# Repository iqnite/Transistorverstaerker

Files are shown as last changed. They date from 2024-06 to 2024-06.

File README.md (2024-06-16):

# TO DO

- [ ] Berechnung
  - [x] Arbeitspunkt-Einstellung
    - [x] Welcher Ib soll verwendet werden (Datenblatt)?
  - [x] Stromverstärker (Basisschaltung)
  - [ ] AC-Berechnung (Ersatzschaltbild)
  - [ ] Kopplungskondensator (Böhmer?)
- [ ] Simulation
- [ ] PCB?
- [ ] Dokumentation

# Downloads

## Zip

**Finales Projekt:** [Herunterladen](https://github.com/iqnite/Transistorverstaerker/archive/refs/heads/main.zip)

**Simulation und Berechnungen:** [Herunterladen](https://github.com/iqnite/Transistorverstaerker/archive/refs/heads/sim.zip)

## Git

**Installation:** `winget install git`

**Einmaliger Download:** `git clone https://github.com/iqnite/Transistorverstaerker.git`

**Update:** 

1. `git fetch`
2. `git pull`

# Struktur

**Altium-Projektordner:** [Transistorverstaerker](https://github.com/iqnite/Transistorverstaerker/tree/sim/Transistorverstaerker)

**OneNote-Notizbuch mit Berechnungen:** [Berechnungen](https://github.com/iqnite/Transistorverstaerker/tree/sim/Berechnungen)

> [!IMPORTANT]
> Das Notizbuch ist nur im [Simulationsteil](https://github.com/iqnite/Transistorverstaerker/tree/sim) verfügbar.

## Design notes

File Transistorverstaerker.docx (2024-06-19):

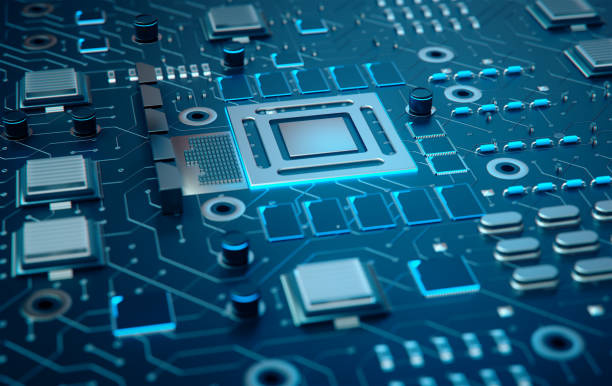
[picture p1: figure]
Elektronischen Chip, 3D-Rendering.

8. Mai 2024

SIMON salchner, Philipp Dona

3ahel/Gruppe 4

BETREUER: ERICH WALTER

ABGEGEBEN AM 19.6.2024

Zweistufiger Transitorverstärker

3. PROJEKT

# 1. Aufgabenstellung

## 1.1 Überblick

Das Ziel dieses Projekts besteht darin, einen zweistufigen Transistorverstärker zu entwerfen. Dieser besteht aus einer spannungsverstärkenden Emitter-Grundschaltung als Stufe 1, und einer stromverstärkenden Kollektor-Grundschaltung als Stufe 2.

## 1.2 Elektrische Vorgaben

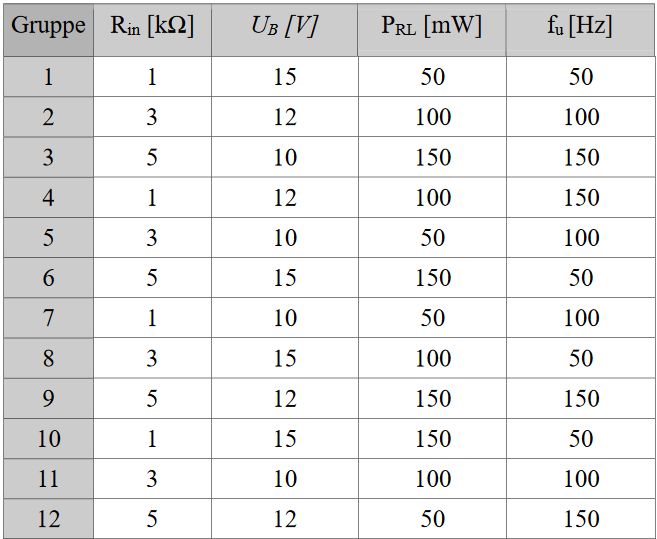
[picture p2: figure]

Die Schaltung wird mit 12 Volt betrieben. Wie in der Zeile 4 dargestellt, muss ein Rin von 1kΩ verwendet werden. Die Leistung am Ausgang PRL soll 100 mW groß sein und die Frequenz fu soll 150 Hz betragen. Ebenfalls war die Vorgabe, die Vu möglichst verzerrungsfrei zu maximieren. Alle weiteren Parameter konnten selbst festgelegt werden und mussten im Berechnungsteil dokumentiert werden.

## 1.3 Sonstige Vorgaben

Beim Erstellen und Aufbau der Schaltung dürfen ausschließlich Bauteile verwendet werden, die im HTL-Bauteilkit enthalten sind.

# 2. Schaltung und Schaltungsbeschreibung

## 2.1 Schaltungsbeschreibung

Diese Schaltung ist ein zweistufiger Transistorverstärker bestehend aus einer Emitter-Grundschaltung gefolgt von einer Kollektorschaltung. Sie besteht aus zwei NPN-Transistoren (BC547A) mit jeweils einem Spannungsteiler (R1/R2 und R3/R4) zur Basisvorspannung. Die Koppel-Kondensatoren C1 und C2 blockieren Gleichstromanteile, während der Bypass-Kondensator Ce die Wechselstromverstärkung erhöht. Jeder Transistor hat einen Kollektorwiderstand (Rc und RL) und einen Emitterwiderstand (Re). Das Eingangssignal (IN) wird verstärkt und am Ausgang (OUT) ausgegeben. Die Schaltung wird mit einer Versorgungsspannung (VCC) betrieben und ist über GND verbunden.

## 2.2 Blockschaltbild

Der erste Block stellt die Spannungsversorgung dar. Das Eingangssignal kommt zuerst in die Spannungsverstärker-Stufe (Emitter-Grundschaltung) und anschließend in die Stromverstärker-Stufe (Kollektorschaltung).

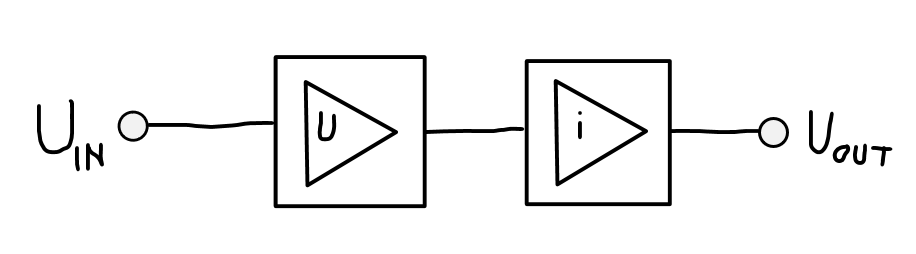
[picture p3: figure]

## 2.3 Gesamt-Schaltplan

## 2.4 Simulations-Schaltung

# 3. Berechnungen

## 3.1 Emitter-Grundschaltung

Vorgaben:

Rin = 1kΩ Ua = UB/2 (Symmetrischer Arbeitspunkt)

Spannungen:

UB = 12V

UBE = 0,7V

URc = 6V

URe = 0,1 * UB = 1,2V

UCE = UB – URc – URe = 12V – 6V – 1,2V = 4,8V

UR2 = URe + Ube = 1,2V + 0,7V = 1,9V

UR1 = UB = UR2 = 12V – 1,9V = 10,1V

Formel für den Eingangswiderstand in Abhängigkeit vom Strom Ic aufstellen. Ic wird berechnet und anschließend die Widerstände.

I_B =(I_C)/B

R_C =(U_(Rc))/(Ic)=(6V)/(Ic)

R_E =(U_(Re))/(Ic)=(1,2V)/(Ic)

R_2 =(U_(R2))/(10*I_B)=(1,9V)/(10*(Ic)/B)=(1,9V*B)/(10*Ic)

R_1 =(U_(R1))/(10*I_B)=(10,1V)/(10*(Ic)/B)=(10,1V*B)/(10*Ic)

r_(BE) =(26mV)/(I_B)=(26mV*B)/(Ic)

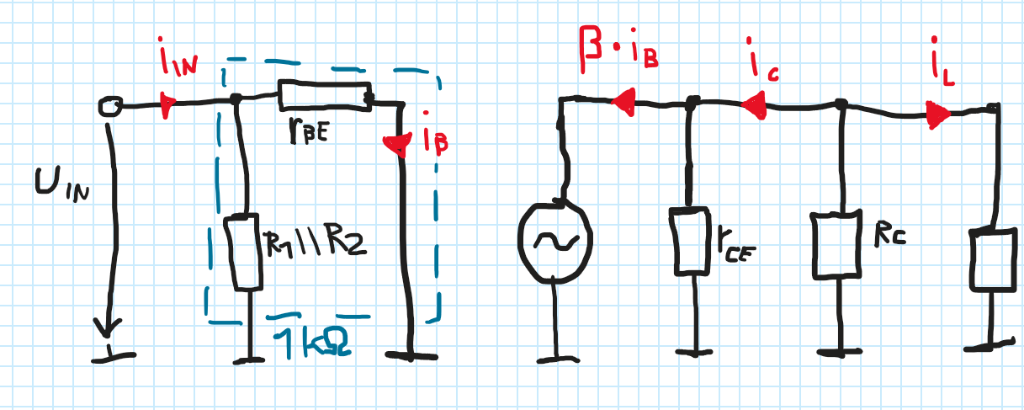
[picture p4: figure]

Gewählt: β=200

r_(in) =1/(1/(R1)+1/(R2)+1/(r_(BE)))= 1/(1/((10,1V* β)/(10* I_C))+ 1/((1,9V* β)/(10* I_C))+1/((26mV* β)/(I_C)))

1/(r_(in))= 1/((10,1V* β)/(10* I_C))+ 1/((1,9V* β)/(10* I_C))+1/((26mV* β)/(I_C))

1/(r_(in))= (10* I_C)/(10,1V* β)+ (10* I_C)/(1,9V* β)+ (I_C)/(26mV* β)

1/(r_(in))= I_C *(10/(10,1V* 200)+ 10/(1,9V* 200)+ 1/(26mV* 200))

1/(r_(in))= I_C *(~223,25m 1/V)

I_C = 1/(r_(in) * 223,25m 1/V)= 1/(1KΩ* 223,25m 1/V) ≈4,479mA

I_B = (I_C)/β= (4,479mA)/200=22,395μA

Widerstandsberechnung:

R_C = (U_(RC))/(I_C)= (6V)/(4,479mA)=1,34kΩ

R_E = (U_(RE))/(I_C)= (1,2V)/(4,479mA)=268Ω

R_2 = (U_(R2))/(10* I_B)= (1,9V)/(10* (I_C)/β)= (1,9V* β)/(10* I_C)= (1,9V*200)/(10* 4,479mA)≈8,48kΩ

R_1 = (U_(R1))/(10* I_B)= (10,1V)/(10* (I_C)/β)= (10,1V* β)/(10* I_C)= (10,1V*200)/(10* 4,479mA)≈45,01kΩ

r_(BE) = (26mV)/(I_B)= (26mV* β)/(I_C)= (26mV*200)/(4,479mA)≈1,16kΩ

Überprüfen:

r_(in) = 1/(1/(R1)+ 1/(R2)+1/(r_(BE)))= 1/(1/(45,099kΩ)+ 1/(8,484kΩ)+1/(1,161kΩ)) ≈998,63Ω ≈1kΩ

Kondensatoren:

Diese Kondensatoren werden verwendet, um die Gleichspannungsanteile herauszufiltern.

Gewählte Widerstände (E12-Reihe):

Rc = 1,2 kΩ

Re = 270 Ω

R2 = 8,2 kΩ

R1 = 47 kΩ

Arbeitspunkt:

U_(RC) = I_C *R_C =4,479mA*1,2kΩ=5,375V

→U_(aE) =VCC-U_(RC) =12V-5,375V=6,625V

## 3.2 Kollektor-Grundschaltung

Vorgaben:

V_(CC) =12V
f_U =150Hz
u_(BE) =0,7V (Datenblatt)
P_L =100mW

β=200→dB (gewählt);β=(i_(CK))/(i_(BK))⇒i_(BK) =(i_(CK))/β
U_L =(V_(CC))/2=6V

P_L =(U_L^2)/(R_L)
⇒R_L =(U_L^2)/(P_L)=360Ω
i_(CK) =(U_L)/(R_L)≈16,67mA

i_(BK) =(i_(CK))/β=83,35μA
R_3 =β*(U_L +u_(BE))/(10*i_(CK))≈8,04kΩ
R_4 =β*(V_(CC) -U_1)/(10*i_(CK))≈26,52kΩ

Gewählte Widerstände (E12-Reihe):

R3 = 8,2kΩ

R4 = 27kΩ

RL = 180Ω + 180Ω

## 3.3 Verstärkung

V_U =(u_L)/(u_Q) r_(INK) =R_3 ||R_4 ||(r_(BE) +R_L )=1/(1/(1,34kΩ)+1/(26,52kΩ)+1/(1,16kΩ+360Ω))≈649Ω u_L =-β*i_B *R_C ||r_(INK) u_Q =i_B *r_(BE) V_U =(-β*i_B *R_C ||r_(INK))/(i_B *r_(BE))=-β*(R_C ||r_(INK))/(r_(BE))=-200*1/(1,16kΩ)*1/(1/(1,34kΩ)+1/(649Ω))≈-75,39→V

# 4. Simulation

## 4.1 Emitter-Grundschaltung

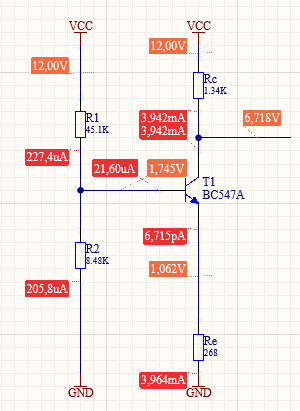
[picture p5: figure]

Bezeichnung | Sollwert | Istwert | Abweichung
Ua | 6,625V | 6,718 | 1,4%
Ic | 4,479mA | 3,942mA | 12%
IB | 22,395uA | 21,6uA | 3,5%
B | 200 | 182,5 | 8,8%

Diskussion: Geringe Abweichung bei der Spannung, bei den Strömen liegt ein größerer Unterschied vor, weil der Transistor in Altiums Simulationsprogramm ein wenig anders ist als der aus dem Bauteilset, daher stimmen die Simulationswerte nicht genau mit den Datenblattwerten überein.

## 4.2 Kollektor-Grundschaltung

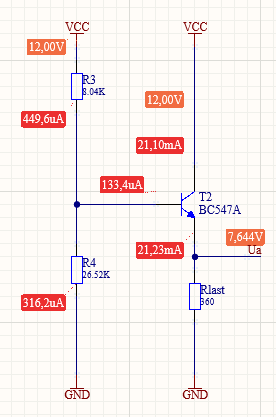
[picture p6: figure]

Bezeichnung | Sollwert | Istwert | Abweichung
Ua | 6V | 7,644V | 21,5%
Ic | 16,67mA | 21,1mA | 21%
IB | 83,35uA | 133,4uA | 37,5%
B | 200 | 158 | 21%

Diskussion: Hier wirkt sich neben dem Ic auch der Ib direkt auf die Ausgangsspannung aus, weshalb die Werte von Ua stark abweichen. Dies liegt auch daran, dass die Spannungsverstärkung von Kollektorgrundschaltungen sehr klein ist.

## 4.3 Verstärkung

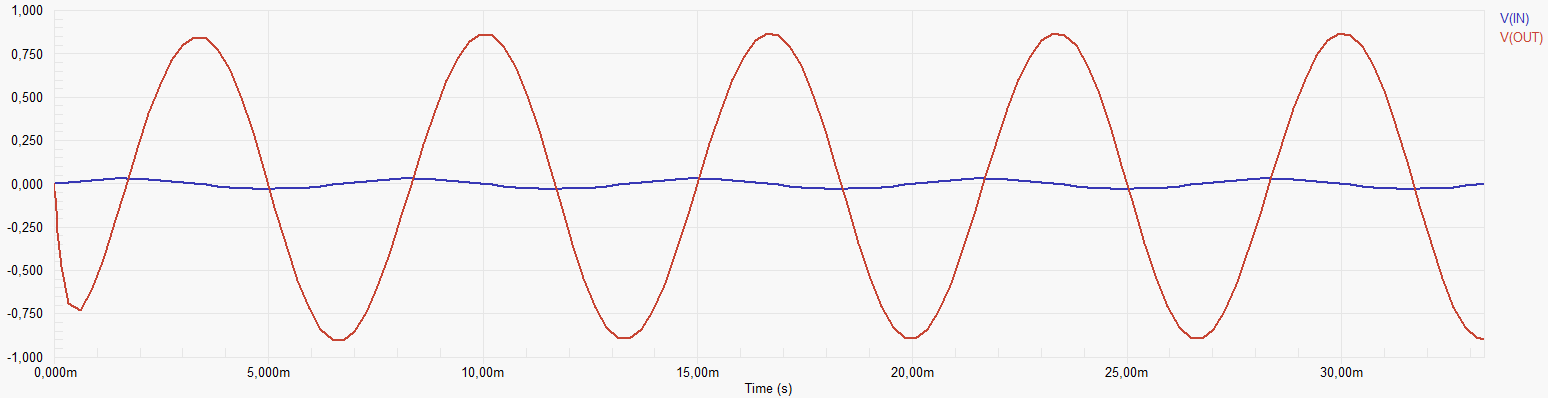
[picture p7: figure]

V_U =(U_(OUT))/(U_(IN))=(-850mV)/(10mV)=-85→V

Diskussion: Die Abweichung zur berechneten Verstärkung entsteht aufgrund der bereits beschriebenen Abweichung der Ströme.

Grenzfrequenzen: 1kHz und 14,9MHz

# 5. Fertigungsunterlagen

Serviceplan

Bestückung

Verdrahtung

Bohrung

# 6. Stückliste

# | Designator | Bezeichnung | Wert | Stückzahl | Händlerlink | Artikel- nummer

| IC
1 | IC1 | LM324 | - | 1 | Bauteilbox | -
| Kondensatoren
2 | C1 | Kondensator | 10 nF/ 50V | 1 | Bauteilbox | -
| Widerstände
3 | 2xR1, R2, 2xR3 | Kohleschichtwiderstand | 1 kΩ/ ¼ W | 5 | Bauteilbox | -
4 | R_PWM1,2 | Kohleschichtwiderstand | 3,3 kΩ/ ¼ W | 2 | Bauteilbox | -
5 | R_PWM2 | Kohleschichtwiderstand | 3,9 kΩ/ ¼ W | 1 | Bauteilbox | -
6 | Rver+, Rver- | Kohleschichtwiderstand | 10 kΩ/ ¼ W | 2 | Bauteilbox | -
| Potentiometer
7 | P1 | Potentiometer | 10 kΩ/ 0,25 W | 1 | Bauteilbox | -
| Buchsen
8 | +9V | Header 2 | - | 1 | Bauteilbox | -
| Br, Bd, Bp | BNC | - | 3 | - | -

# 7. Datenblätter

Simon Salchner, Philipp Doná Seite 2 von 21

Zweistufiger Transistorverstärker 3AHEL

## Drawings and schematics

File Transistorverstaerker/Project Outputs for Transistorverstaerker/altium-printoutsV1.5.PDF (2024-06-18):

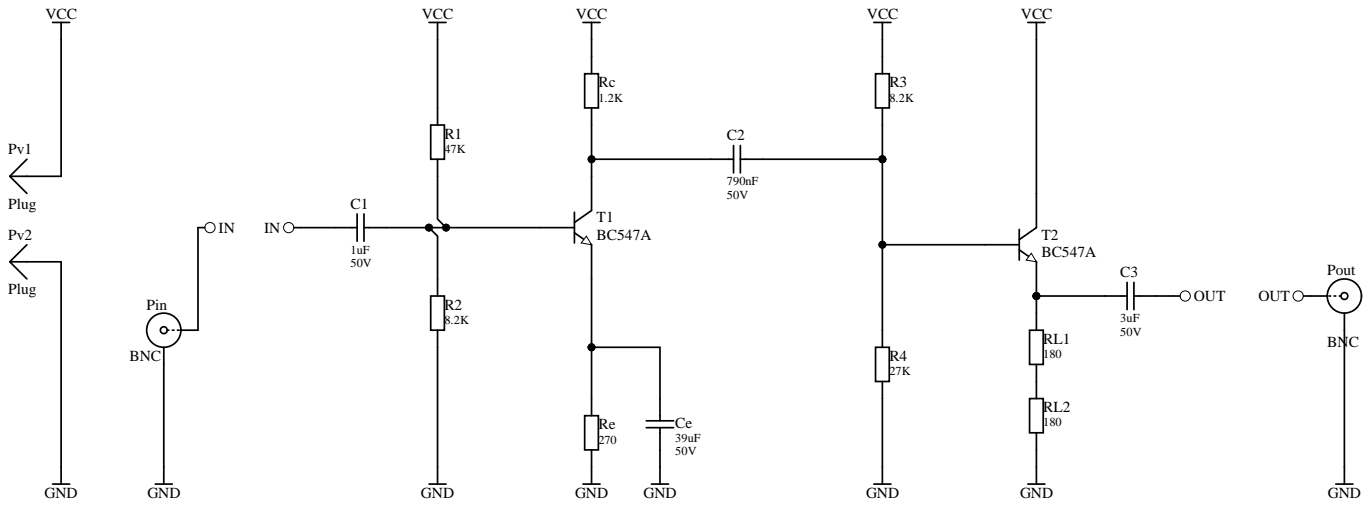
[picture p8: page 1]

Philipp Dona, Simon Salchner
Titel:
Transistorverst
Entwurf Zweistufig

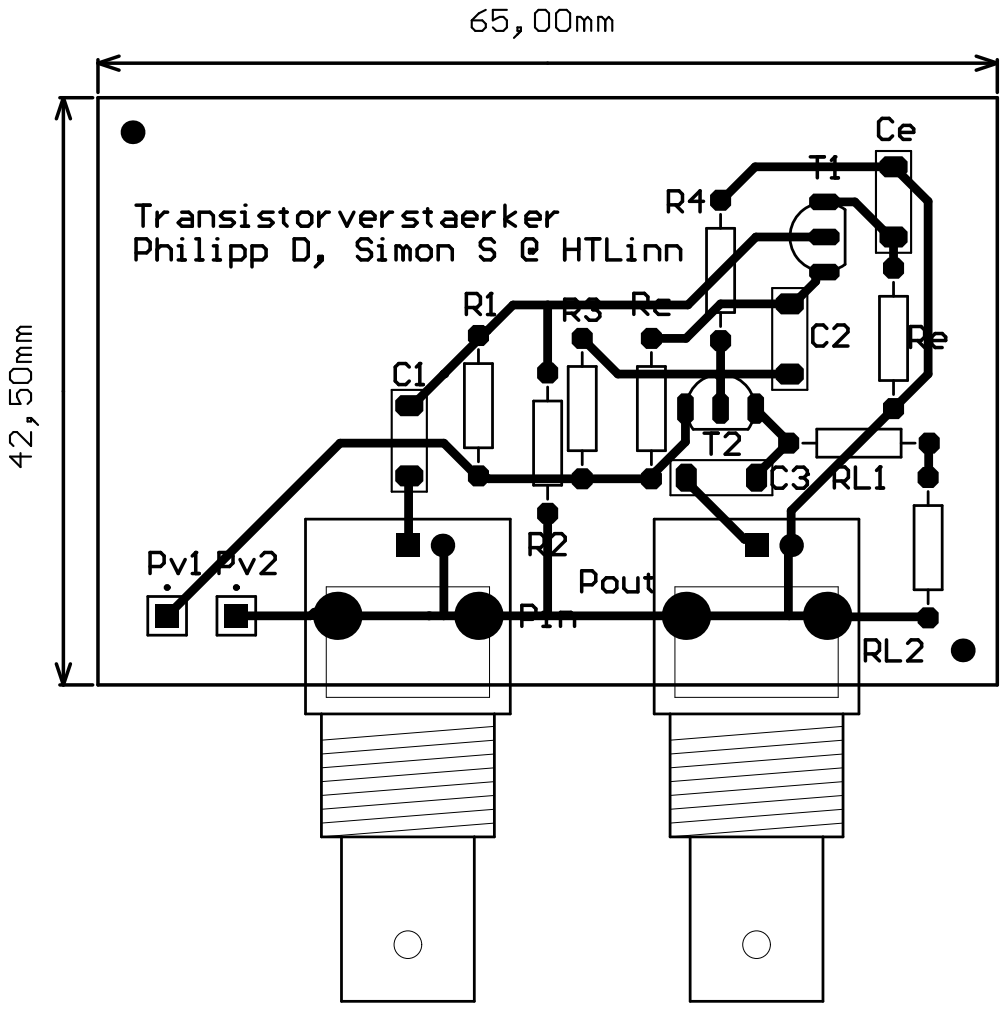
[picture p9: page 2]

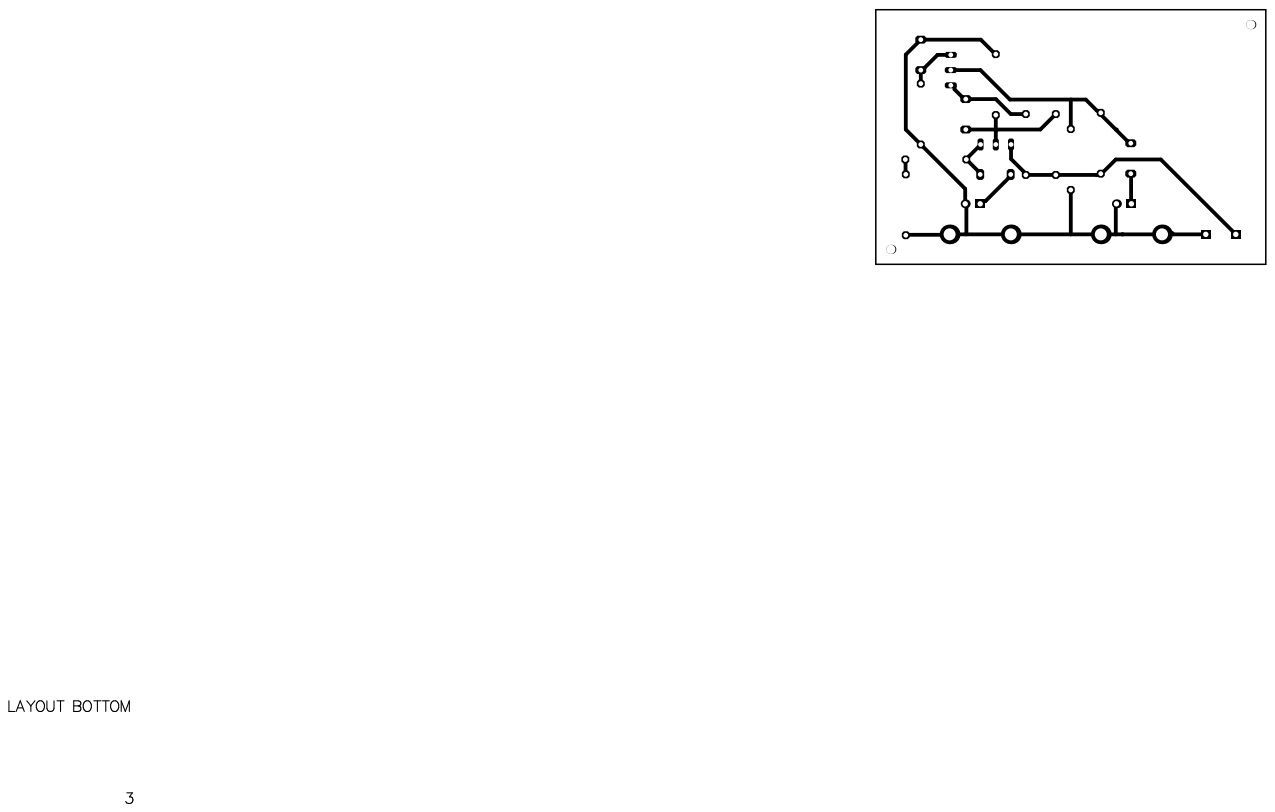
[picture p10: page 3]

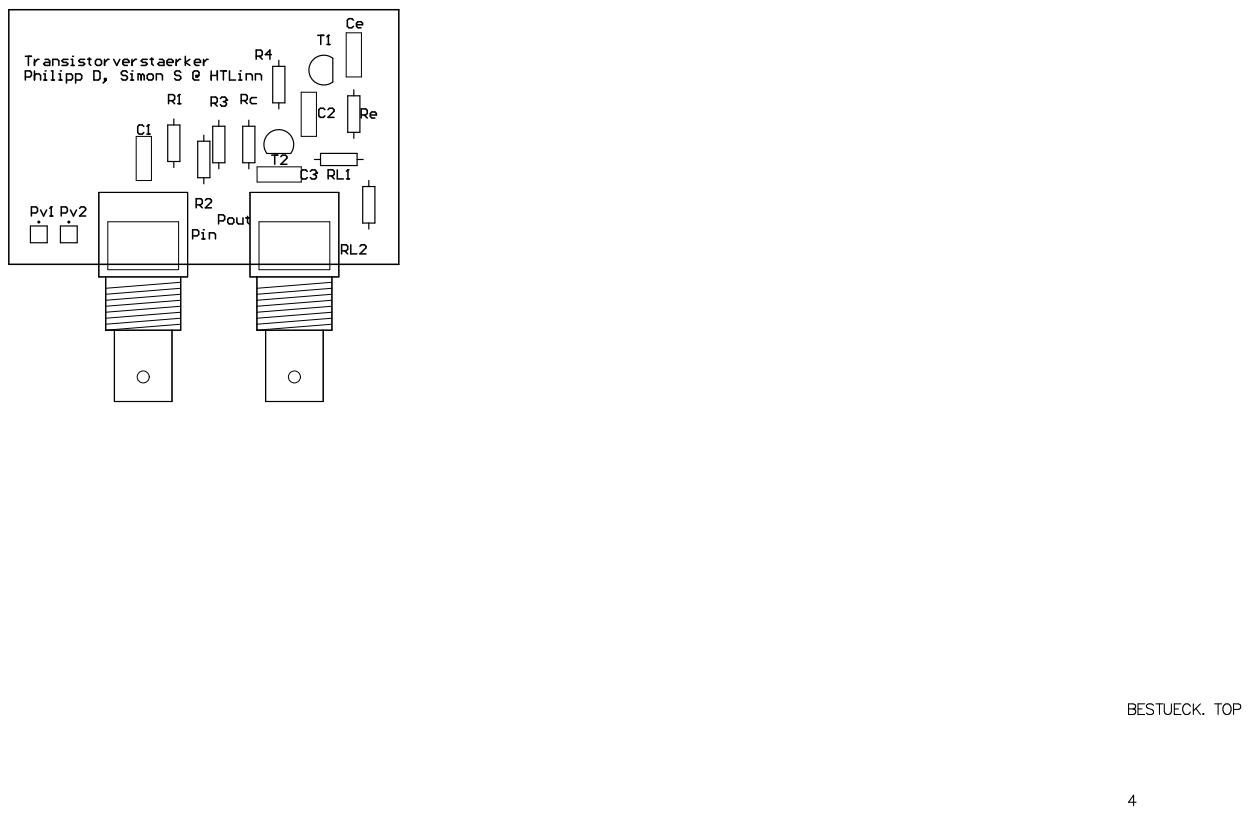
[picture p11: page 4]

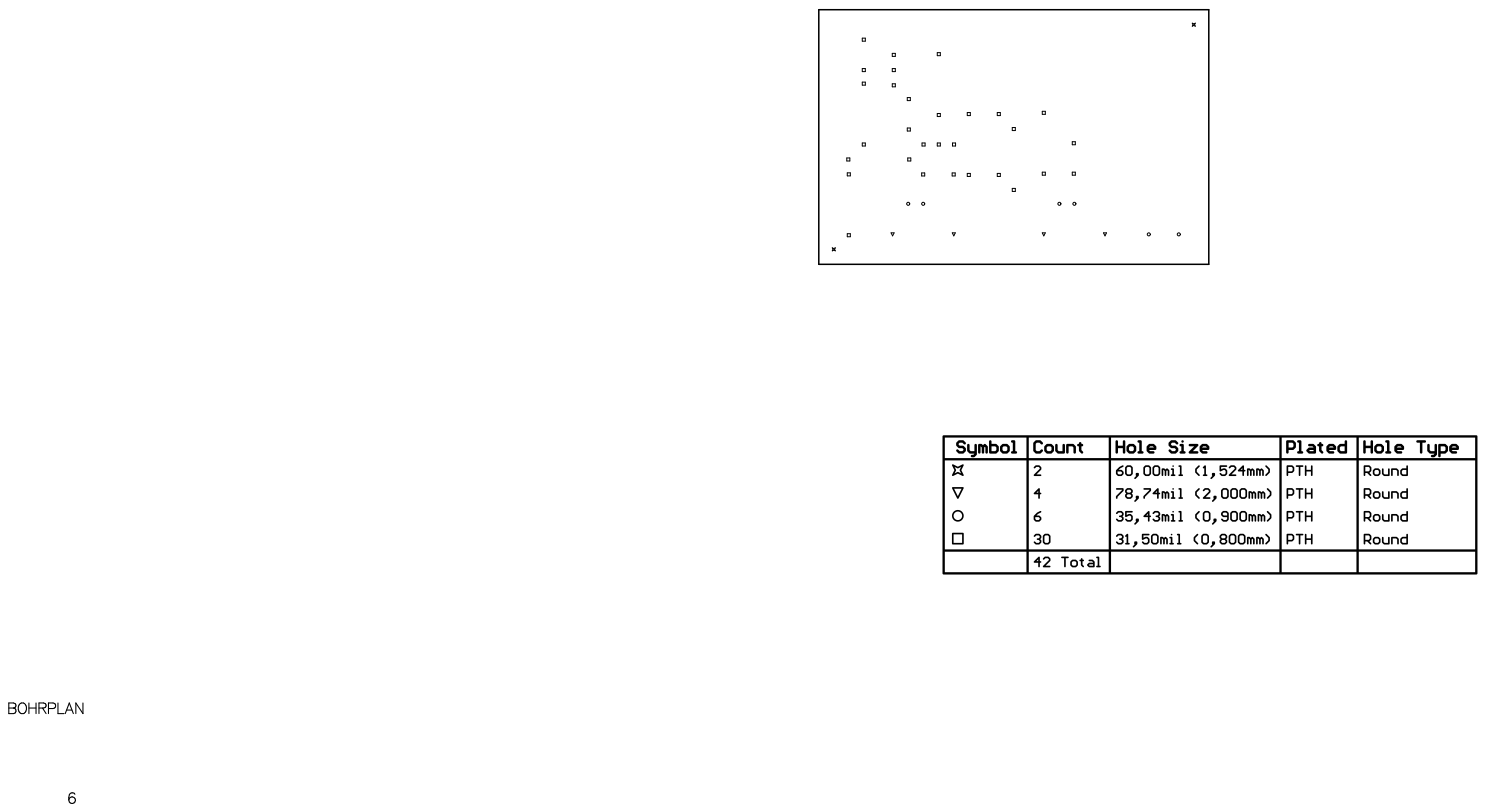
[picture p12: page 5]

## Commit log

2024-06-11 Adapt schematic
    [Transistorverstaerker.PrjPcb, Transistorverstaerker.SchDoc]
2024-06-11 Remove Rlast from final schematic
    [Transistorverstaerker.PrjPcb]
2024-06-11 Remove Rlast from final schematic (1)
    [Transistorverstaerker.SchDoc]
2024-06-16 Finish PCB
    [Transistorverstaerker.PcbDoc, Transistorverstaerker.PrjPcb, Transistorverstaerker.SchDoc]
2024-06-16 Finish Output Job File
    I'm f-ckin dying
    [Transistorverstaerker.PcbDoc, Transistorverstaerker.PrjPcb]
2024-06-18 Finish project
    [Transistorverstaerker.PcbDoc, Transistorverstaerker.SchDoc]
2024-06-18 Update final
    [Transistorverstaerker.PcbDoc, Transistorverstaerker.SchDoc]
